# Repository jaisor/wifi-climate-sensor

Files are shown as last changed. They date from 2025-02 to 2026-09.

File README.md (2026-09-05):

# WiFi Climate Sensor

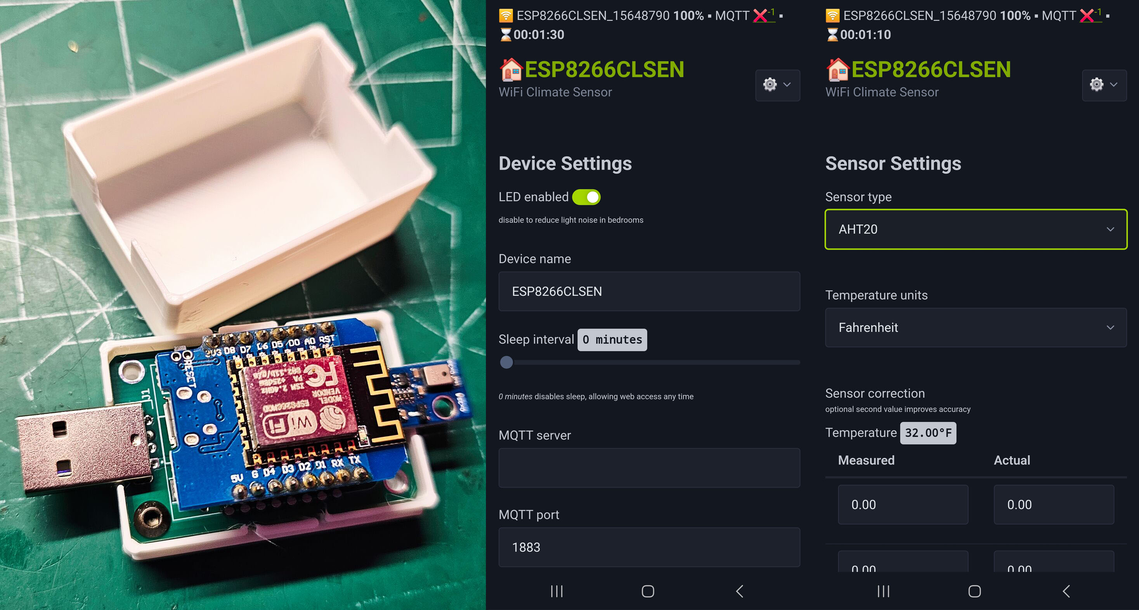
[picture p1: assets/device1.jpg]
device1


Supported features:
* ESP8266, ESP32, ESP32-C3 or ESP32-S3 based
* Built-in web server with UI for sensor reading and configuration
* Selectable temperature/humidity sensor: AHT20, BME280, BME688, DHT22, DS18B20
* BME688 adds barometric pressure, gas resistance and an estimated Indoor Air Quality index
* I2C autodetection of the AHT20, BME280 and BME688, selected and saved automatically on boot
* Optional INA219 I2C power monitor for bus voltage and current, auto-detected at boot
* MQTT support for transmitting sensor data
* Home Assistant MQTT auto-discovery for temperature, humidity, pressure, gas resistance, air quality, voltage, current and power sensors
* OTA firmware update using ElegantOTA at `/update`
* OTA firmware update triggered via MQTT config topic
* 3D printed case for clean and seamless mounting

# Usage

## Initial boot / reset

Compile for your select ESP architecture and flash over USB.

On first boot the device creates a self-hosted WiFi access point (AP) with SSID starting with `ESP8266CLSEN` or `ESP32CLSEN` and WPA2 password `password123`
In self-hosted AP mode, the device gives itself `192.168.4.1` IP address.

The device can be connected to an existing AP using the `/wifi` option

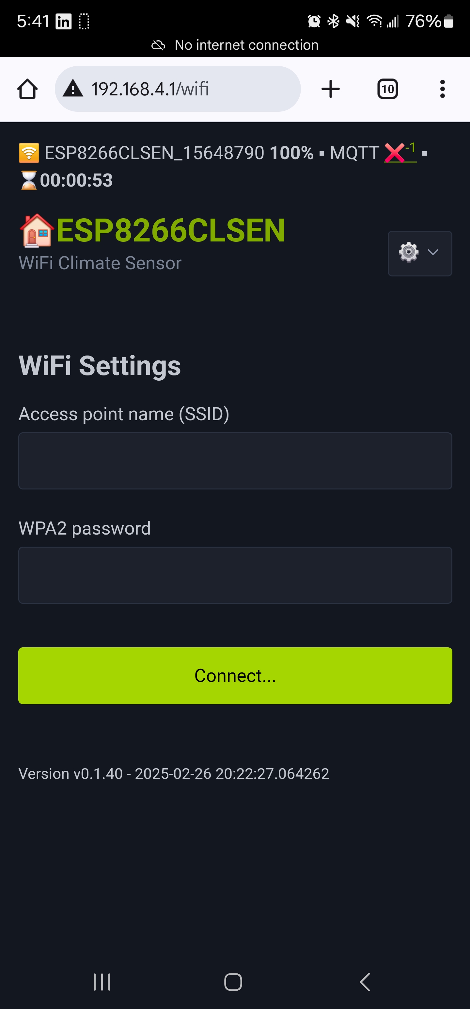
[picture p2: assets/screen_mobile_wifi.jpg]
wifi screenshot


## Resetting / erasing configuration

The device will reset itself to default configuration and self-hosted AP if unable to complete its boot sequence within 2 seconds (smooth boot) 3 times in a row.
This can be forced by power-cycling the device several times. Powered up durations should be about 1 second (less than 2 second, but enough for the CPU to start). 

# Climate sensor autodetection

On boot the I2C bus is probed for the two climate sensors that live on it, and the first match is selected and
persisted to EEPROM, so a freshly flashed board generally needs no sensor configuration at all:

| Sensor | Addresses probed | Chip id at `0xD0` |
|---|---|---|
| BME280 | `0x76`, then `0x77` | `0x60` |
| BME688 | `0x76`, then `0x77` | `0x61` |
| AHT20 | `0x38` | - |

The BME280 and BME688 share the same two addresses, so an address probe alone cannot tell them apart. The chip id
register `0xD0` is read to decide, and anything else there (a BMP280 reports `0x58`) is logged and skipped rather
than misreported. Whichever address answered is remembered, so a sensor strapped to `0x77` is opened on `0x77`.

The BME680 and BME688 both report chip id `0x61` and use the same driver. The variant register `0xF0` separates
them (`0x01` is the BME688) and only affects the name shown in the UI and published over MQTT.

Autodetection only overrides the stored setting when nothing is configured yet, or when the configured sensor is
itself an I2C one that no longer answers - swapping a BME280 for an AHT20 is picked up on the next boot. An explicit
DS18B20 or DHT22 selection is never overridden, since neither is on the I2C bus. Set `TEMP_SENSOR_AUTODETECT` in
[Configuration.h](src/Configuration.h) to turn the whole thing off and go back to choosing the sensor by hand.

Note that on the ESP32-C3 the DS18B20 data pin and `SCL` are the same GPIO. When a DS18B20 is selected the I2C bus
is never started, so neither autodetection nor the INA219 runs on that target.

# BME688 air quality

The BME688 is wired to the same I2C pins as the AHT20 and BME280 and reports four values: temperature, humidity,
barometric pressure and gas resistance. All four appear on the main page and in the MQTT payload; pressure is also
reported by the BME280.

Gas resistance is published raw in ohms as `gas_resistance_ohms` and shown in kilohms on the web page. Higher
resistance means cleaner air.

## Indoor Air Quality index

The raw resistance is also run through an IAQ estimator in [AirQuality.cpp](src/AirQuality.cpp), which reports on the
same 0-500 scale BSEC uses (lower is cleaner):

| IAQ | Rating |
|---|---|
| 0-50 | Excellent |
| 51-100 | Good |
| 101-150 | Lightly polluted |
| 151-200 | Moderately polluted |
| 201-250 | Heavily polluted |
| 251-350 | Severely polluted |
| 351-500 | Extremely polluted |

**This is not Bosch BSEC.** BSEC is a closed-source binary with its own licence and its output cannot be reproduced
from the public datasheet. This estimator has the same shape and reports the same quantity on the same scale, but the
values are not interchangeable with BSEC's. Three steps:

1. **Humidity and temperature compensation.** Gas resistance falls as water vapour rises, independently of air
   quality. Temperature and relative humidity are converted to absolute humidity in g/m3 via the Magnus formula, and
   the reading is lifted back out with `gas * exp(0.03 * absolute_humidity)`. Using absolute rather than relative
   humidity is what makes the correction hold across different temperatures.
2. **Baseline tracking.** The compensated value feeds a clean-air reference that rises towards cleaner readings with
   a 5 minute time constant but decays towards dirtier ones over a day. The asymmetry is the point: a fast decay
   would quietly adopt a persistently polluted room as the new "clean" reference. Adaptation is driven by elapsed
   time rather than sample count, so the read interval does not change the tuning.
3. **Scoring.** 75% of the score is how close the compensated reading sits to the baseline, 25% is how close humidity
   is to an ideal 40%RH. The combined 0-100 score is inverted onto the 0-500 IAQ scale.

The main page shows all of this in one **Gas & Air Quality** panel: the index and its rating, the raw resistance, the
humidity-compensated value with the absolute humidity used to correct it, the current clean-air baseline, and how long
the estimator has been tracking. Below that is a sparkline of the index and the baseline over the last 12 hours, one
point every 15 minutes. That history is kept in RAM only and restarts on reboot - unlike the baseline itself, which is
persisted; a buffer that size written at that cadence would wear the flash for little benefit. A device that deep
sleeps will collect points slowly, one per wake at most.

`iaq_accuracy` mirrors BSEC's field of the same name and says how far the baseline has settled: `0` stabilizing
(the first 5 minutes are discarded while the heater drifts), `1` uncertain, `2` calibrating after 10 minutes, `3`
calibrated after 30. Treat the index as meaningless until it reads at least `2`.

### Surviving restarts and deep sleep

The baseline and the total tracked time are persisted in the configuration, so a restart or a deep sleep cycle
continues the same calibration instead of starting from nothing. Three things make that work:

- **Elapsed time is credited on wake.** The baseline decays on elapsed time, and a sleeping device is only awake for
  a few seconds per cycle, so without this its day-scale decay would take months of real time. On wake the configured
  `deepSleepDurationSec` is added to the next reading's time delta. Over a simulated 24h of sustained pollution a
  device sleeping on a 5 minute interval lands on IAQ 249 against 251 for an always-on one; uncredited it would
  report 316 and barely move its baseline.
- **A resumed session skips the burn-in.** The 5 minute burn-in exists for the heater's initial drift on a cold
  start. A resumed session already has a trusted baseline, so it only discards the first couple of seconds - a
  sleeping device is rarely awake long enough for more.
- **Writes are rate limited.** The baseline is saved at most every 30 minutes and only once it has moved more than
  2% (`IAQ_PERSIST_INTERVAL_MS` and `IAQ_PERSIST_DELTA`), plus once unconditionally just before entering deep sleep.
  Saving on every reading would wear the flash for no benefit.

The persisted fields are appended to `configuration_t` *after* the `_loaded` sentinel on purpose. The sentinel keeps
its offset, so this firmware still accepts configuration written by a build that predates the IAQ block rather than
treating it as blank and resetting your settings; the appended bytes then read back as erased flash, which the
`iaqMagic` marker catches so only the IAQ state is reinitialized.

Two limits remain. Time spent fully powered off is not measured - only the configured sleep interval is credited, so
a device off for a week resumes as though it slept one interval. And an index built on a self-calibrating baseline is
relative to that sensor's own history; compare a device against itself over time, not against another unit.

The heater runs at `BME688_GAS_HEATER_TEMP_C` for `BME688_GAS_HEATER_MS` (320C for 150ms by default, both in
[Configuration.h](src/Configuration.h)). Because that makes a measurement take a few hundred milliseconds, readings
are taken asynchronously with `beginReading()`/`endReading()` so the main loop is never blocked waiting on the heater.

# Power monitoring (INA219)

An optional [INA219](https://www.ti.com/product/INA219) high side current/voltage monitor can be wired to the I2C bus.
It is probed at address `0x40` on every boot: when present its readings show up as a **Power** card on the main page
below temperature and humidity, and in the MQTT payload. When absent the card is omitted entirely and the sensor is
skipped with no further effect. The `/sensor` page splits its settings into an **Environment Sensor** area and a
**Power Sensor** area, each showing the detected sensor name and its pin or I2C address.

These readings are independent of the `voltage_v` value, which is still sampled through the ADC voltage divider.
The INA219 reports the voltage across its own shunt, so the two can be wired to different rails.

| Board | SDA | SCL |
|---|---|---|
| ESP32-C3 | `GPIO7` | `GPIO6` |
| ESP32-S3 | `GPIO8` | `GPIO9` |
| ESP32 / ESP8266 | core default | core default |

Pins are set by `I2C_SDA_PIN` / `I2C_SCL_PIN` in [Configuration.h](src/Configuration.h), and the I2C address by
`INA219_I2C_ID`. The bus is shared with the BME280, AHT20 and OLED peripherals.

# MQTT

## Sensor data

The device publishes a JSON payload to `{mqttTopic}/json` every 5 minutes. Example payload:

```json
{
  "device_id": 12345678,
  "temperature": 21.5,
  "temperature_unit": "Celsius",
  "humidity": 55.2,
  "pressure_hpa": 1013.2,
  "gas_resistance_ohms": 142300,
  "iaq": 32.5,
  "iaq_rating": "Excellent",
  "iaq_accuracy": 3,
  "iaq_accuracy_text": "calibrated",
  "voltage_v": 12.1,
  "ina219_voltage_v": 12.043,
  "ina219_current_ma": 184.2,
  "ina219_power_mw": 2218.3,
  "wifi_rssi": -67,
  "wifi_percent": 66,
  "timestamp_iso8601": "2026-05-28T12:00:00Z",
  "uptime_millis": 300000
}
```

## Home Assistant auto-discovery

On every MQTT publish the device sends Home Assistant MQTT discovery messages, automatically registering the following entities under a single device:

| Entity | Discovery topic |
|---|---|
| Temperature | `homeassistant/sensor/{deviceId}_temperature/config` |
| Humidity | `homeassistant/sensor/{deviceId}_humidity/config` |
| Pressure | `homeassistant/sensor/{deviceId}_pressure/config` |
| Gas resistance | `homeassistant/sensor/{deviceId}_gas_resistance/config` |
| Air quality (IAQ) | `homeassistant/sensor/{deviceId}_iaq/config` |
| Air quality accuracy | `homeassistant/sensor/{deviceId}_iaq_accuracy/config` |
| Voltage | `homeassistant/sensor/{deviceId}_voltage/config` |
| INA219 Voltage | `homeassistant/sensor/{deviceId}_ina219_voltage/config` |
| INA219 Current | `homeassistant/sensor/{deviceId}_ina219_current/config` |
| INA219 Power | `homeassistant/sensor/{deviceId}_ina219_power/config` |

No manual configuration in Home Assistant is required — enable MQTT integration and the device will appear automatically.

## Remote configuration

Publish a JSON payload to `{mqttTopic}/{deviceId}/config` to update configuration at runtime:

```json
{
  "name": "Living Room Sensor",
  "deepSleepDurationSec": 300,
  "ledEnabled": true,
  "tempUnit": 0
}
```

The retained message is deleted immediately after receipt to prevent re-applying on reconnect.

## OTA firmware update over MQTT

Publish a JSON payload to `{mqttTopic}/{deviceId}/config` with a `firmware_location` key to trigger a firmware update:

```json
{ "firmware_location": "http://my-server/firmware_device_.bin" }
```

The substring `_device_` in the URL is replaced with the target architecture before the download:

| Board | Replacement |
|---|---|
| ESP8266 | `ESP8266` |
| ESP32 | `ESP32` |
| ESP32-C3 | `ESP32C3` |
| ESP32-S3 | `ESP32S3` |

So `firmware_device_.bin` becomes e.g. `firmware_ESP32C3_.bin`. The device reboots automatically on a successful update.

The ESP can also be upadted over web OTA at `/update` after the device IP.

# Schematic, PCB and assembly

[Schematic and PCB available online](https://a360.co/4gnvt9p)

[Gerber files uploaded here](https://365.altium.com/files/86EDE8C7-B795-499B-9DB7-9364AABE9626)

[Gedber files direct download](assets/gerber.zip)

[Schematic EAGLE sch file](assets/schematic_eagle.sch)

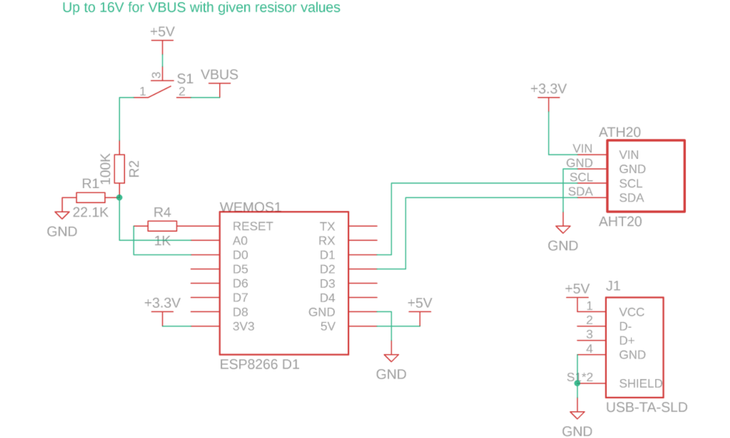
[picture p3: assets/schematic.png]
Schematic

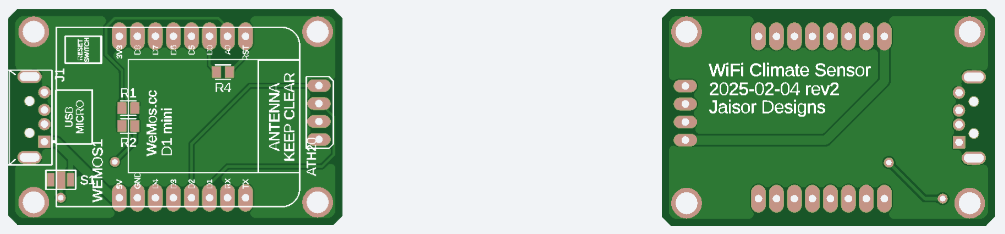
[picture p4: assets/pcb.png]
PCB


# Case
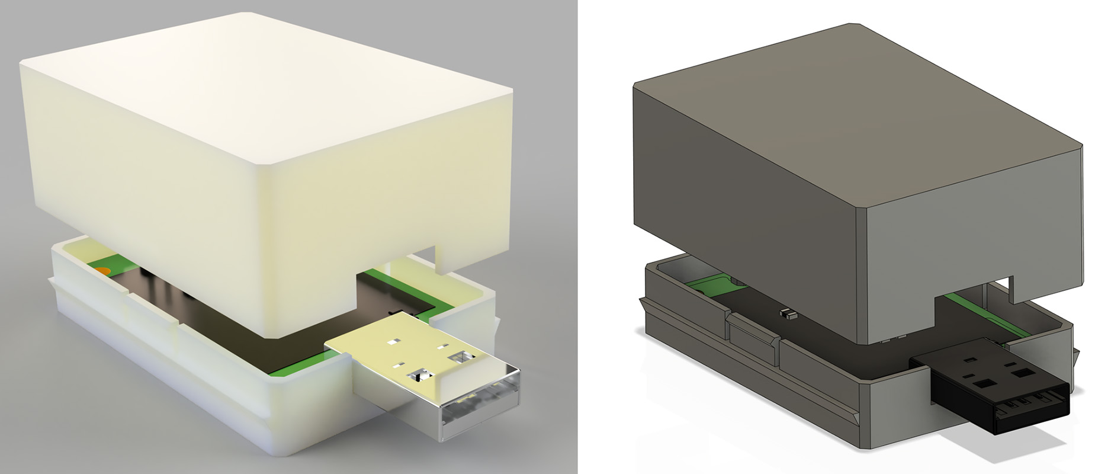
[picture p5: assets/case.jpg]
case preview


STL files:
* [bottom](assets/case_bottom.stl)
* [top](assets/case_top.stl) - if too tight fitting, scale top up by 1%

# Apache proxy setup

Example configuration for exposing a local network device via Apache proxy. Strong advise to use SSL/HTTPS and appropriate authentication and authorization controls to reduce risk of bad actors. 

```
                <Location /ac>
                        AuthType Basic
                        Authname "Password Required"
                        AuthUserFile /etc/apache2/.htpasswd
                        Require valid-user
                </Location>

                ProxyPass /ac/roomname http://192.168.x.y disablereuse=On
                ProxyPassReverse /ac/roomname http://192.168.x.y
```

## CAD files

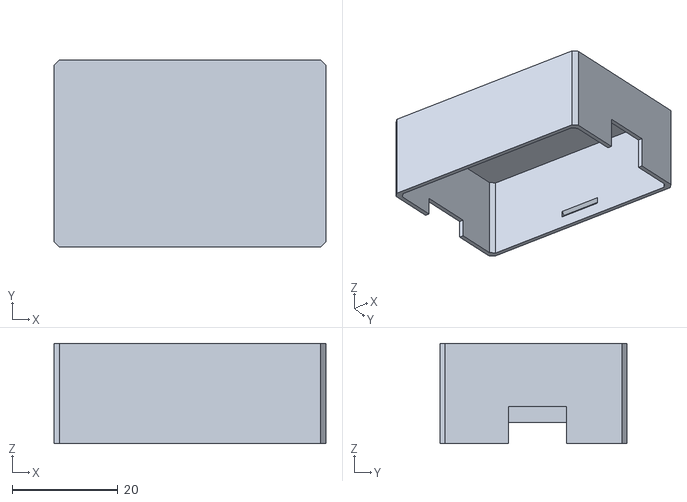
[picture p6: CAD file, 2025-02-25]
assets/case_top.stl
51.5 x 35.5 x 19.0

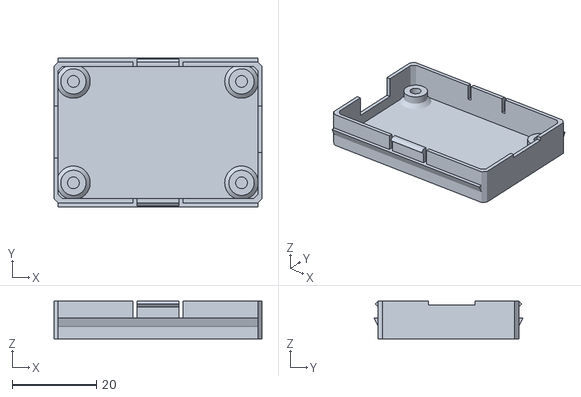
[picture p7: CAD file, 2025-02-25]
assets/case_bottom.stl
49.5 x 35.5 x 9.00

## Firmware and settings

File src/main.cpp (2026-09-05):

#include <Arduino.h>
#include <ArduinoLog.h>

#if !( defined(ESP32) ) && !( defined(ESP8266) )
  #error This code is intended to run on ESP8266 platform! Please check your Tools->Board setting.
#endif

#include "Configuration.h"
#include "wifi/WifiManager.h"
#include "Device.h"

#ifdef ESP32
#elif ESP8266
  ADC_MODE(ADC_TOUT);
#endif

CWifiManager *wifiManager;
CDevice *device;

unsigned long tsSmoothBoot;
bool smoothBoot;
unsigned long tsMillisBooted;

void goToSleep() {
  #ifdef TEMP_SENSOR
  // Last chance to save the IAQ baseline; deep sleep loses everything not in flash
  device->persistAirQuality(true);
  #endif
  WiFi.disconnect();
  // WiFi.forceSleepBegin((uint64_t)configuration.deepSleepDurationSec * 1e6);

  #ifdef ESP32
    digitalWrite(INTERNAL_LED_PIN, LOW);
    SPI.end();  //remove if not using SPI
    Wire.end(); //remove if not using I2C
    pinMode(SS, INPUT_PULLUP );
    pinMode(6, INPUT_PULLUP );
    pinMode(4, INPUT_PULLUP );
    pinMode(8, INPUT_PULLUP );
    pinMode(9, INPUT_PULLUP );
    pinMode(1, INPUT_PULLUP );
    pinMode(2, INPUT_PULLUP );
    pinMode(3, INPUT_PULLUP );
    pinMode(0, INPUT_PULLUP );
    pinMode(5, INPUT_PULLUP );
    #ifdef CONFIG_IDF_TARGET_ESP32C3
      esp_sleep_enable_timer_wakeup((uint64_t)configuration.deepSleepDurationSec * 1e6);
      delay(1);
      esp_deep_sleep_start();
    #else
      ESP.deepSleep((uint64_t)configuration.deepSleepDurationSec * 1e6);
    #endif
  #elif ESP8266
    digitalWrite(INTERNAL_LED_PIN, HIGH);
    ESP.deepSleep((uint64_t)configuration.deepSleepDurationSec * 1e6); 
  #endif
  delay(1000);
}

void setup() {

  randomSeed(analogRead(0));
  
  #ifdef ESP8266
    pinMode(D0, WAKEUP_PULLUP);
  #endif
  pinMode(INTERNAL_LED_PIN, OUTPUT);
  intLEDOn();

  #ifndef DISABLE_LOGGING
  Serial.begin(SERIAL_MONITOR_BAUD);
  // Bounded wait. On the USB-CDC targets (ESP32-C3/S3) Serial only becomes true once a
  // terminal attaches, so an unbounded `while (!Serial)` stops setup() from ever reaching
  // loop() - and loop() is where the factory reset counter is cleared, so three headless
  // boots in that state wipe the stored configuration.
  unsigned long tsSerial = millis();
  while (!Serial && millis() - tsSerial < 3000) { delay(10); }
  delay(100);
  Log.begin(LOG_LEVEL, &Serial);
  Log.infoln(F("\n\nInitializing..."));
    #ifdef WEB_LOGGING
    Log.addHandler(&logStream);
    Log.infoln(F("Initializing web log..."));
    #endif
  #elif defined(WEB_LOGGING)
    Log.begin(WEB_LOG_LEVEL, &logStream);
    Log.infoln(F("Initializing web log..."));
  #endif

  if (EEPROM_initAndCheckFactoryReset() >= 3) {
    Log.warningln("Factory reset conditions met!");
    EEPROM_wipe();  
  }

  tsSmoothBoot = millis();
  smoothBoot = false;

  EEPROM_loadConfig();

  Log.infoln("Configuration loaded");
  
  device = new CDevice();
  wifiManager = new CWifiManager(device);
  #ifdef OLED
  wifiManager->setDisplay(device->display());
  #endif

  if (wifiManager->isError()) {
    Log.errorln("wifiManager->isError()=%i", wifiManager->isError());
    while(true) {
      intLEDBlink(250);
      delay(250);
    }
  }

  Log.infoln("Initialized");
}

void loop() {
  
  if (!smoothBoot && millis() - tsSmoothBoot > FACTORY_RESET_CLEAR_TIMER_MS) {
    smoothBoot = true;
    EEPROM_clearFactoryReset();
    tsMillisBooted = millis();
    if (configuration.deepSleepDurationSec == 0) {
      // Keep the LED on if expected to sleep
      intLEDOff();
    }  
    Log.noticeln("Device booted smoothly!");
  }

#ifdef OLED
  device->display()->clearDisplay();
#endif

  device->loop();
  wifiManager->loop();

#ifdef OLED
  device->display()->display();
#endif

  if (wifiManager->isRebootNeeded()) {
    return;
  }

  // Conditions for deep sleep:
  // - Min time elapsed since smooth boot (to catch up on any MQTT messages)
  // - Smooth boot
  // - Wifi not in AP mode
  // - Succesfully submitted 1 sensor reading over MQTT
  if (smoothBoot 
    && configuration.deepSleepDurationSec > 0 
    && millis() - tsMillisBooted > DEEP_SLEEP_MIN_AWAKE_MS
    && wifiManager->isJobDone() ) {
      delay(100);
      intLEDOff();
      Log.noticeln("Initiating deep sleep for %u sec", configuration.deepSleepDurationSec );
      goToSleep();
  }

  if (configuration.deepSleepDurationSec > 0 && device->getUptime() > configuration.deepSleepDurationSec * 1000) {
    Log.noticeln("Device is not sleeping right, resetting to save battery");
    #ifdef ESP32
      ESP.restart();
    #elif ESP8266
      ESP.reset();
    #endif
  }
 
  yield();
}

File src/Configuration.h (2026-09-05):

#pragma once

#include <Arduino.h>
#include <functional>
#include <ArduinoLog.h>
#include <StreamUtils.h>

//#define DEBUG_MOCK_HP
//#define DISABLE_LOGGING
#ifndef DISABLE_LOGGING
  #define LOG_LEVEL LOG_LEVEL_INFO
#endif

#define WEB_LOGGING // When enabled log is available at http://<device_ip>/log
#ifdef WEB_LOGGING
  #define WEB_LOG_LEVEL LOG_LEVEL_VERBOSE
#endif

#ifdef CONFIG_IDF_TARGET_ESP32C3
  #define SERIAL_MONITOR_BAUD 460800
  #define DISABLE_LOGGING // Xiao's setup with USB requires serial to be initialized on the IDE else it blocks
#else
  #define SERIAL_MONITOR_BAUD 115200
#endif

#define EEPROM_FACTORY_RESET 0       // Byte to be used for factory reset device fails to start or is rebooted within 1 sec 3 consequitive times
#define EEPROM_CONFIGURATION_START 1   // First EEPROM byte to be used for storing the configuration

#define FACTORY_RESET_CLEAR_TIMER_MS 2000   // Clear factory reset counter when elapsed, considered smooth boot

#if defined(ESP32)
  #define DEVICE_NAME "ESP32CLSEN"
#elif defined(ESP8266)
  #define DEVICE_NAME "ESP8266CLSEN"
#endif

#define WIFI
#ifdef WIFI
  #define WIFI_SSID DEVICE_NAME
  #define WIFI_PASS "password123"

  // If unable to connect, it will create a soft accesspoint
  #define WIFI_FALLBACK_SSID DEVICE_NAME // device chip id will be suffixed
  #define WIFI_FALLBACK_PASS "password123"

  #define NTP_SERVER "pool.ntp.org"
  #define NTP_GMT_OFFSET_SEC -25200
  #define NTP_DAYLIGHT_OFFSET_SEC 0

  // Web server
  #define WEB_SERVER_PORT 80
#endif

#define VOLTAGE_SENSOR  // ADC A0 using 0-3.3v voltage divider
#ifdef VOLTAGE_SENSOR
  #define VOLTAGE_SAMPLES 10 // Number of samples to take for averaging
  #define VOLTAGE_DIVIDER_VALUE 57.2 // 162.3 - 4.2v max; 57.2 - 14.8v max;
  #if defined(CONFIG_IDF_TARGET_ESP32C3)
    #define VOLTAGE_SENSOR_ADC_PIN  GPIO_NUM_3
  #elif defined(ESP32)
    #define VOLTAGE_SENSOR_ADC_PIN  A0
  #elif defined(ESP8266)
    #define VOLTAGE_SENSOR_ADC_PIN  A0
  #elif defined(SEEED_XIAO_M0)
    #define VOLTAGE_SENSOR_ADC_PIN  D1
  #else
    #define VOLTAGE_SENSOR_ADC_PIN  0
  #endif
#endif

// I2C bus shared by the BME280, AHT20, INA219 and OLED peripherals.
// Only targets that need non-default pins are listed; the rest use the core defaults.
#if defined(CONFIG_IDF_TARGET_ESP32C3)
  // ESP32C3 uses GPIO 6,7 for SDA,SCL - see https://wiki.seeedstudio.com/XIAO_ESP32C3_Getting_Started/
  #define I2C_SDA_PIN GPIO_NUM_7
  #define I2C_SCL_PIN GPIO_NUM_6
#elif defined(CONFIG_IDF_TARGET_ESP32S3)
  #define I2C_SDA_PIN GPIO_NUM_8
  #define I2C_SCL_PIN GPIO_NUM_9
#endif

#define CURRENT_SENSOR  // INA219 high side voltage/current monitor on I2C, auto-detected at boot
#ifdef CURRENT_SENSOR
  #define INA219_I2C_ID 0x40
  #define CURRENT_SENSOR_DELAY_MS 500 // Minimum interval between INA219 readings
#endif

#define TEMP_SENSOR
#ifdef TEMP_SENSOR
  #define TEMP_UNIT_CELSIUS 0
  #define TEMP_UNIT_FAHRENHEIT 1
  #define BME280_SEALEVELPRESSURE_HPA (1013.25)
  #define BME280_I2C_ID 0x76
  #define BME280_I2C_ID_ALT 0x77 // Adafruit and some other breakouts strap the address line high
  #define AHT20_I2C_ID 0x38
  // The BME688 shares 0x76/0x77 with the BME280, so the two are told apart by the chip id
  // register rather than by address alone.
  #define BOSCH_REG_CHIP_ID 0xD0
  #define BOSCH_CHIP_ID_BME280 0x60
  #define BOSCH_CHIP_ID_BME68X 0x61
  #define BME68X_REG_VARIANT 0xF0
  #define BME68X_VARIANT_BME688 0x01 // 0x00 is the BME680, which the same driver handles
  #define BME688_GAS_HEATER_TEMP_C 320
  #define BME688_GAS_HEATER_MS 150
  // Marks the persisted IAQ block as written by this firmware rather than left over
  #define IAQ_STATE_MAGIC 0x1A9BA5E1
  #define IAQ_PERSIST_INTERVAL_MS 1800000UL // Save the baseline at most every 30 min
  #define IAQ_PERSIST_DELTA 0.02f           // ...and only once it moved more than 2%
  #define TEMP_SENSOR_AUTODETECT // Probe the I2C bus for a BME280/AHT20 and select it automatically
  #if defined(CONFIG_IDF_TARGET_ESP32C3)
    #define TEMP_SENSOR_PIN GPIO_NUM_6
  #elif defined(ESP32)
    #define TEMP_SENSOR_PIN 0
  #elif defined(ESP8266)
    #define TEMP_SENSOR_PIN D3
  #elif defined(SEEED_XIAO_M0)
    #define TEMP_SENSOR_PIN D4
  #endif
#endif

//#define OLED
#ifdef OLED
  #define OLED_SCREEN_WIDTH 128 // OLED display width, in pixels
  #define OLED_SCREEN_HEIGHT 32 // OLED display height, in pixel
  #define OLED_I2C_ID  0x3C
#endif

#if defined(CONFIG_IDF_TARGET_ESP32C3)
  #define INTERNAL_LED_PIN GPIO_NUM_8
#else
  #define INTERNAL_LED_PIN LED_BUILTIN
#endif


#define DEEP_SLEEP_INTERVAL_SEC 300 // 5 min
#define DEEP_SLEEP_MIN_AWAKE_MS 5000 // Minimum time to remain awake after smooth boot
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

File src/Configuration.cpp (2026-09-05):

#include <Arduino.h>
#include <EEPROM.h>
#include <version.h>
#include "Configuration.h"

configuration_t configuration;
#ifdef WEB_LOGGING
  StringPrint logStream;
#endif

// NOTE: these used to wrap EEPROM.commit() in taskENTER_CRITICAL/taskEXIT_CRITICAL. The
// spinlock was a local, so it never excluded anything, but disabling interrupts across an
// NVS flash write (and across logging) tripped the interrupt watchdog on the dual core
// parts - "Interrupt wdt timeout on CPU1" during boot. The EEPROM calls are safe as-is.
uint8_t EEPROM_initAndCheckFactoryReset() {
  Log.noticeln("Configuration size: %i", sizeof(configuration_t));
  
  EEPROM.begin(sizeof(configuration_t) + EEPROM_FACTORY_RESET + 1);
  uint8_t resetCounter = EEPROM.read(EEPROM_FACTORY_RESET);

  Log.noticeln("Factory reset counter: %i", resetCounter);
  Log.noticeln("EEPROM length: %i", EEPROM.length());

  // Bump reset counter
  EEPROM.write(EEPROM_FACTORY_RESET, resetCounter + 1);
  EEPROM.commit();

  return resetCounter;
}

void EEPROM_clearFactoryReset() {
  EEPROM.write(EEPROM_FACTORY_RESET, 0);
  EEPROM.commit();
}

void EEPROM_saveConfig() {
  Log.infoln("Saving configuration to EEPROM");
  EEPROM.put(EEPROM_CONFIGURATION_START, configuration);
  Log.verboseln("Committing EEPROM");
  EEPROM.commit();
}

void EEPROM_loadConfig() {

  configuration = {};
  EEPROM.get(EEPROM_CONFIGURATION_START, configuration);

  Log.noticeln("Configuration loaded: %s", configuration._loaded);

  //strcpy(configuration.wifiSsid, "");
  //strcpy(configuration.wifiPassword, "");

  if (strcmp(configuration._loaded, "jaisor")) {
    // blank
    Log.infoln("Blank configuration, loading defaults");
    strcpy(configuration._loaded, "jaisor");
    strcpy(configuration.name, DEVICE_NAME);
    configuration.ledEnabled = true;
    #ifdef WIFI
      strcpy(configuration.ntpServer, NTP_SERVER);
      configuration.gmtOffset_sec = NTP_GMT_OFFSET_SEC;
      configuration.daylightOffset_sec = NTP_DAYLIGHT_OFFSET_SEC;
      strcpy(configuration.mqttServer, "");
      configuration.mqttPort = 1883;
      strcpy(configuration.mqttTopic, "");
      #if defined(CONFIG_IDF_TARGET_ESP32C3) || defined(CONFIG_IDF_TARGET_ESP32S3)
        configuration.wifiPower = 34; // ESP32-C3 default: WIFI_POWER_8_5dBm (8.5dBm)
      #else
        configuration.wifiPower = 82;
      #endif
    #endif

    #ifdef VOLTAGE_SENSOR
      configuration.voltageDivider = VOLTAGE_DIVIDER_VALUE;
    #endif
    #ifdef TEMP_SENSOR
      configuration.tempSensor = TEMP_SENSOR_UNSUPPORTED;
      configuration.tempUnit = TEMP_UNIT_FAHRENHEIT;
      memset(configuration.tCorrection, 0, 2 * sizeof(sensorCorrection));
      memset(configuration.hCorrection, 0, 2 * sizeof(sensorCorrection));
      configuration.iaqMagic = 0;
      configuration.iaqBaseline = 0;
      configuration.iaqAccumulatedSec = 0;
    #endif

    configuration.deepSleepDurationSec = 0;

    EEPROM_saveConfig();
  }

#ifdef WIFI
  String wifiStr = String(configuration.wifiSsid);
  for (auto i : wifiStr) {
    if (!isAscii(i)) {
      Log.verboseln("Bad SSID, loading default: %s", wifiStr.c_str());
      strcpy(configuration.wifiSsid, "");
      break;
    }
  }
#endif

#if defined(TEMP_SENSOR)
  // Written by a build without the IAQ block, or never written at all: drop it and start the
  // baseline over rather than scoring against erased flash. The rest of the config is intact.
  if (configuration.iaqMagic != IAQ_STATE_MAGIC) {
    Log.infoln("No stored IAQ baseline, starting a fresh one");
    configuration.iaqMagic = IAQ_STATE_MAGIC;
    configuration.iaqBaseline = 0;
    configuration.iaqAccumulatedSec = 0;
  } else {
    Log.noticeln("Restored IAQ baseline %F Ohm after %u tracked seconds",
      configuration.iaqBaseline, configuration.iaqAccumulatedSec);
  }
#endif

  Log.noticeln("Device name: %s", configuration.name);
  Log.noticeln("Version: %s", VERSION);
}

void EEPROM_wipe() {
  Log.warningln("Wiping configuration with size %i!", EEPROM.length());
  for (uint16_t i = 0; i < EEPROM.length() ; i++) {
    EEPROM.write(i, 0);
  }
  EEPROM.commit();
}

uint32_t CONFIG_getDeviceId() {
    // Create AP using fallback and chip ID
  uint32_t chipId = 0;
  #ifdef ESP32
    for(int i=0; i<17; i=i+8) {
    chipId |= ((ESP.getEfuseMac() >> (40 - i)) & 0xff) << i;
    }
  #elif ESP8266
    chipId = ESP.getChipId();
  #endif

  return chipId;
}

String CONFIG_getChipModel() {
  #ifdef ESP32
    return ESP.getChipModel();
  #elif ESP8266
    return "ESP8266";
  #endif
}

uint8_t CONFIG_getChipRevision() {
  #ifdef ESP32
    return ESP.getChipRevision();
  #elif ESP8266
    return 0; // not exposed by the ESP8266 core
  #endif
}

uint32_t CONFIG_getFlashChipSize() {
  #ifdef ESP32
    return ESP.getFlashChipSize();
  #elif ESP8266
    return ESP.getFlashChipRealSize();
  #endif
}

static unsigned long tMillisUp = millis();
unsigned long CONFIG_getUpTime() {  
  return millis() - tMillisUp;
}
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

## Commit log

2025-01-28 adding temp sensor code and aht20 support
    [Configuration.h]
2025-02-02 readme and html experiments
    [schematic_eagle.sch]
2025-02-03 html updates work in device
2025-02-04 working AHT sensor code, displayis on web site
2025-02-04 separated sensor settings, added temp correction func in settings
    [Configuration.h]
2025-02-06 OLED support for 128x32 i2c module
    [Configuration.h]
2025-02-09 work on sensor correctino values
    [Configuration.h]
2025-02-10 Working sensor correction
2025-02-13 Sensor settings, correction and voltage divider done
    [Configuration.h]
2025-02-15 crashing and not waking up frmo sleep properly
    [Configuration.h]
2025-02-15 debugging deep sleep issue which turned out to be hadrware on this batch of ESP8266 D1s - requiring a 10K resisor between GPIO7 and 3v3
    [Configuration.h]
2025-02-24 added versioning fixed AsyncWeb library conflict issues
    [Configuration.cpp, WifiManager.cpp]
2025-02-25 sensor type configurable
    [Configuration.h, case_bottom.stl, case_top.stl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]
2025-03-09 json tweaks, start on esphome layout (not working)
    [Device.cpp, WifiManager.cpp, main.cpp]
2025-07-19 serial logging fixes for esp32c3
    [Configuration.h]
2025-07-21 Fix for EPROM writing, and I2C ports for ESPC3
    [Configuration.h]
2025-07-25 code complete for ESP32C3 and tested on a prototype build
    [Configuration.h]
2025-07-27 voltage samling and averaging
    [Configuration.h]
2025-08-03 ESP8266 compatibility
    [Configuration.h]
2025-08-16 tweaks and fixes for bug in pcb swapping SDA and SCL
    [Configuration.h]
2025-08-16 implemented wifi tx power to offset ESP32C3 antenna issue
    [Configuration.h]
2025-08-20 Fixed uppercase for includes that only works on Windows
    [WifiManager.cpp]
2025-08-22 build num increase only on release, and wifi power support for 8266
2025-08-27 tweaks to the flow to start using semvers and fix a big in wifi power for 8266
    [WifiManager.cpp]
2025-09-14 DS18B20 sensor fixes
    [Configuration.h]
2025-09-20 fix: Refactor versioning system: remove build number handling, update versioning format, and clean up version.h
    [WifiManager.cpp]
2025-11-04 fix: fixed support for esp8266 and correctly disabling TEMP_SENSOR
    [Device.cpp, WifiManager.cpp]
2025-11-11 fix: ESP32C3 change to use GPIO3 for voltage as GPIO2 has a pullup getting in the way
    [Configuration.h]
2025-11-11 fix: ESP8266 compile error fix
    [Device.cpp]
2026-04-19 fix: response size, wifi power level for esp32c3
    [Configuration.cpp, WifiManager.cpp]
2026-05-04 fix: wifi manager library compatiblity
    [WifiManager.cpp]
2026-05-29 fix: library version update
    [Configuration.cpp]
2026-05-29 fix: add temp sensor type in mqtt and updates to README
    [WifiManager.cpp]
2026-08-27 Power Meter Sensor support
    [Configuration.h]
2026-08-27 feat: power sensor support fix: logging and crash stability improvements
    [Configuration.h]
2026-08-29 fix: stamp the pushed tag into tagged release builds
    SEMVER was passed as `SEMVER=... && pio run`, which is a plain shell
    assignment and never reaches the child process. buildscript_versioning.py
    therefore always fell through to its dev.<timestamp> branch, so every
    tagged release was stamped as a dev build. Pass it through the step
    `env:` block instead, in both workflows.
    Additionally for the tag release workflow:
    - version now comes from the pushed tag (github.ref_name) rather than
    semver-action's computed "next", which is meaningless for a tag build
    - built binaries are attached to the release, which previously had none
    - release creation moved out of the matrix so the per-board jobs no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
2026-08-30 feat: showing device chip information
    [Configuration.h]
2026-09-05 feat: BME68x (BME688/BME680) climate sensor support
    Adds the BME688 alongside the AHT20 and BME280 on the same I2C pins,
    reporting all four of its measurements: temperature, humidity, barometric
    pressure and gas resistance.
    The BME688 answers on 0x76/0x77, the same addresses as the BME280, so
    probing addresses alone cannot tell them apart. Autodetection now reads
    chip id register 0xD0 to decide (0x60 BME280, 0x61 BME68x) and logs and
    skips anything else, so a BMP280 reporting 0x58 is no longer assumed to
    be a BME280 and only rejected later inside the driver. The BME680 and
    BME688 share chip id 0x61, so variant register 0xF0 is read to label the
    part honestly rather than calling every BME68x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
    [Configuration.h]
2026-09-05 feat: estimated Indoor Air Quality index from BME68x gas resistance
    Runs the BME688 gas resistance through an IAQ estimator and surfaces it on
    the main page, over MQTT and as Home Assistant discovery topics. The raw
    resistance reading is kept and unchanged alongside it.
    This is not Bosch BSEC. BSEC is a closed-source binary with its own licence
    whose output cannot be reproduced from the public datasheet. This estimator
    has the same shape, reports the same quantity on the same 0-500 scale and
    uses the same accuracy semantics, but the values are not interchangeable
    with BSEC's. The UI, the README and the header all say so, so it is not
    later mistaken for the real thing.
    The reading is compen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
    [Configuration.h]
2026-09-05 feat: show IAQ and its supporting data in the gas sensor panel
    Folds the separate air quality card into the gas sensor card, so the index
    sits next to the reading it is derived from rather than beside it. The panel
    shows the index and rating, the raw resistance, the humidity compensated
    value together with the absolute humidity used to correct it, the current
    clean air baseline, and how long the estimator has been tracking.
    Adds a real baseline history: a 48 entry ring buffer sampled every 15 min,
    so 12 hours, drawn as an inline SVG sparkline with the index on a fixed
    0-500 axis and the baseline faint behind it. The baseline is scaled to its
    own range because only its shape is meaningful at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
    [WifiManager.cpp]
